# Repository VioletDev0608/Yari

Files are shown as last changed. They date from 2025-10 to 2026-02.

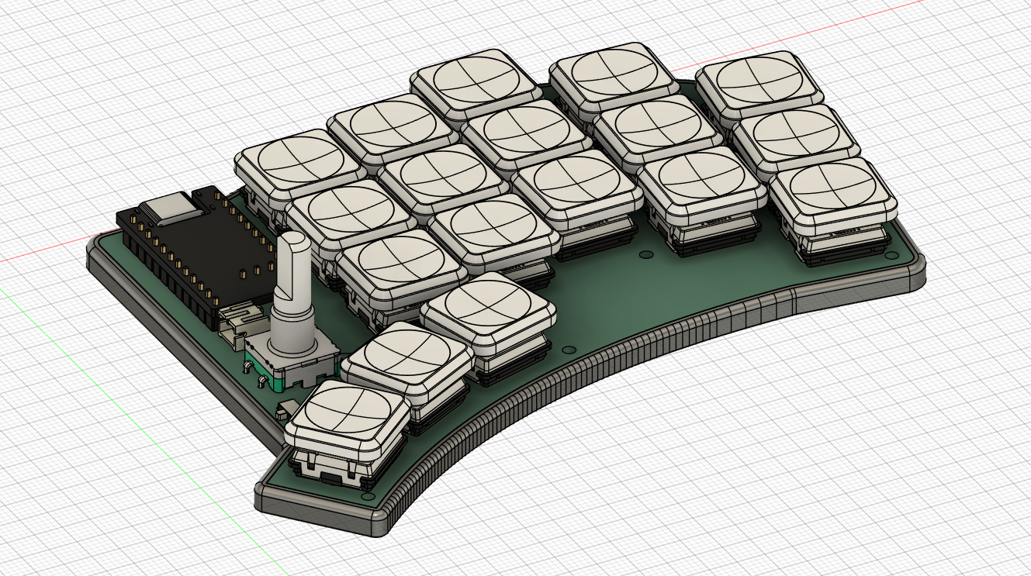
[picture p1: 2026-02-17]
images/image7.png

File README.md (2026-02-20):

# Yari
Yari is a 36-key column-staggered choc split keyboard. It is designed to reduce the required thumb movement beneath the palm.
It has 1 LED to indicate battery levels, splayed pinky and row columns, and is meant to be used with two Supermini nRF52840 microcontrollers. It features an EC11 rotary encoder and extra key on the left half that can be used to switch layers, etc.

## Features:
- 37 Keys
- Column staggered
- Choc v1
- Splayed pinky and row columns
- 1 LED for battery indication
- ZMK support
- Wireless
- EC11 Rotary Encoder

## CAD Model:

The case is a open style with no walls surrounding the switches and just a simple tray to mount the keyboard to and prevent dust from getting into the assembly.
The assembly itself is quite simple
Use a soldering iron to heat up the threaded screw inserts and help it melt its way into the slightly undersized standoff holes. Secure the PCB using the M2 screws. 



Added a version with a split case design with holes at the power button and a cutout at the MCU.


## PCB

PCB was made entirely in Kicad and rotated to minimize the costs when fabricating the PCB. 
There are some quotes on the palm so check it out!





## Firmware

Firmware is based on ZMK!
Hasn't been tested yet...

## BOM

Check [BOM.csv](https://github.com/VioletDev0608/Yari/blob/main/BOM/BOM%20-%20Yari.csv) for all parts needed to build this keyboard!
It comes out to about 98 dollars using aliexpress and JLCPCB to fabricate the PCB!

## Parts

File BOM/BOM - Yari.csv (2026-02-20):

Product Name | Model Name | Quantity | Column 1 | Total Price | Links
PCB |  | 2 |  | $14.00
MCU | Supermini nRF52840 | 2 |  | $9.00 | https://ja.aliexpress.com/item/1005006035267231.html
Switches | Choc V1 | 37 |  | $20.00 | https://ja.aliexpress.com/item/1005008943998118.html
Diodes | 1N4148W(SOD123 Package) | 37 |  | $1.00 | https://ja.aliexpress.com/item/1005008841989543.html
Keycaps | Choc V1 compatible | 37 |  | $15.00 | https://ja.aliexpress.com/item/1005009410193865.html
Reset Button | B3U-1000P | 2 |  | $5.00 | https://ja.aliexpress.com/item/1005007149637345.html
Power Switch | MSK12C02 | 2 |  | $3.00 | https://ja.aliexpress.com/item/1005006710234187.html
Battery | 301230 Lipo Battery | 2 |  | $10.00 | https://ja.aliexpress.com/item/1005008947414547.html
JST connector | JST PH2.0 2 Pin terminal Female socket BENT PIN SOCKET | 2 |  | $3.00 | https://ja.aliexpress.com/item/1005007441813591.html
LED | SK6812mini-e | 2 |  | $2.00 | https://ja.aliexpress.com/item/1005008308801366.html
Sockets | Kalih choc v1 | 37 |  | $5.00 | https://ja.aliexpress.com/item/1005008928238101.html
Rubber feet |  |  |  | $4.00 | https://ja.aliexpress.com/item/1005006455782191.html
Threaded screw inserts | M2x3x3.2 | 34 |  | $3.00 | https://ja.aliexpress.com/item/1005008318533389.html
M2 laptop-style flathead screws | M2x3 | 34 |  | $2.00 | https://ja.aliexpress.com/item/1005008504707668.html
Rotary Encoder | EC11 | 1 |  | $3.00 | https://ja.aliexpress.com/item/1005009120433387.html
Total Price |  |  |  | $99.00
Other stuff needed
3D printed case

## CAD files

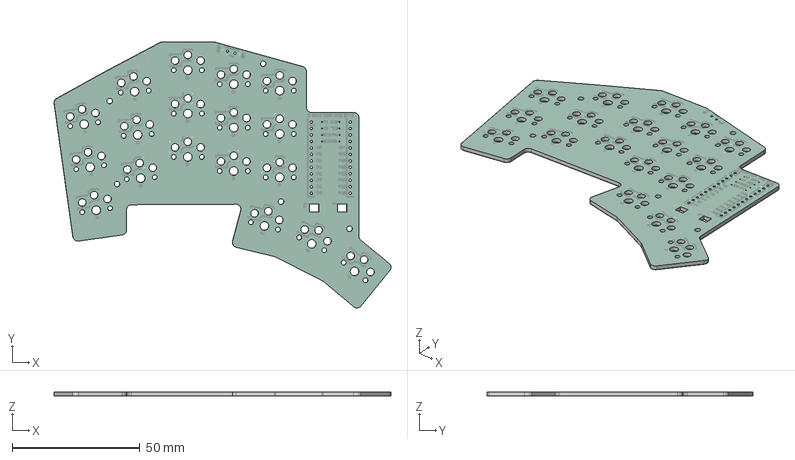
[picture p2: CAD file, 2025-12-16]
CAD/assembled.step
132.0 x 104.2 x 1.66 mm

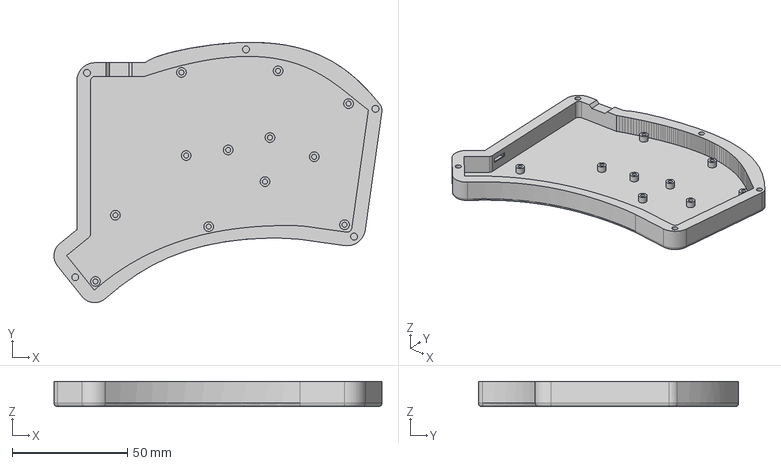
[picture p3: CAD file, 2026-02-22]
CAD/Right Top Case Bottom.step
142.0 x 112.7 x 11.0 mm

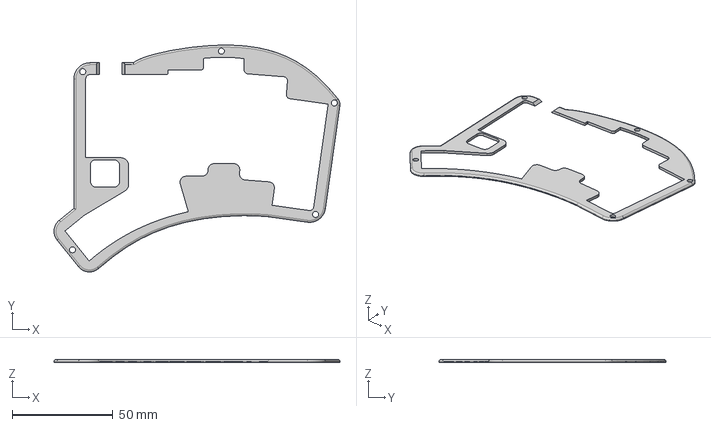
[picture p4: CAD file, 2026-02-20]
CAD/Right Top Case Top.step
142.0 x 112.7 x 1.50 mm

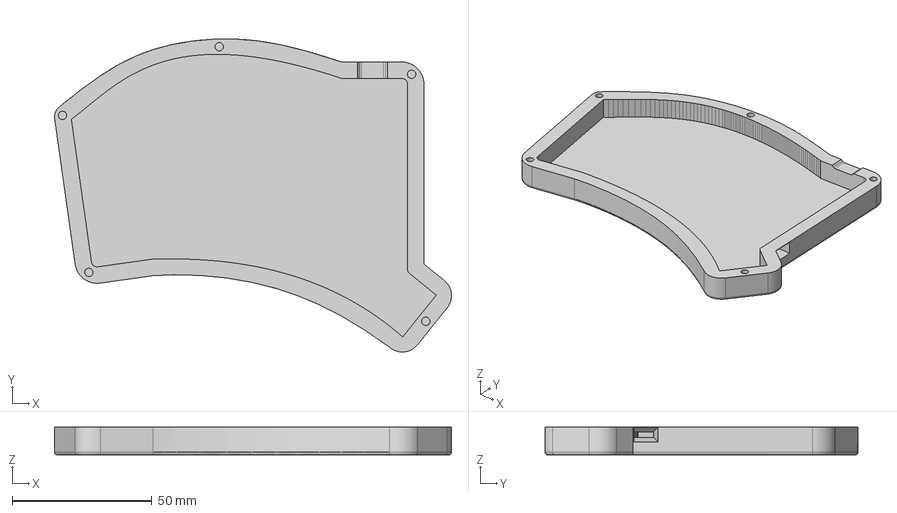
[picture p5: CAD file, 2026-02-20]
CAD/Left Top Case Bottom.step
142.2 x 112.1 x 10.0 mm

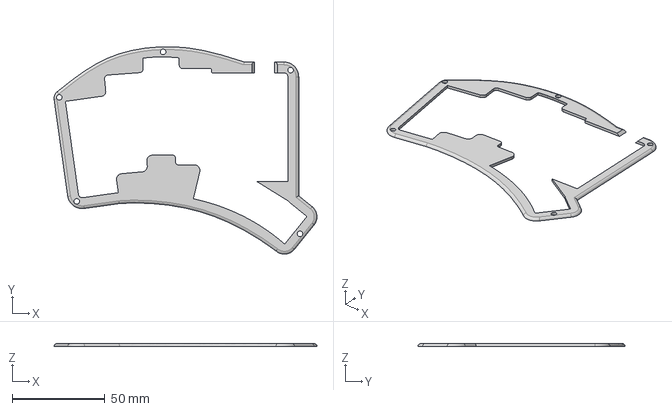
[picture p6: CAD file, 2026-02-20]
CAD/Left Top Case Top.step
142.2 x 112.1 x 1.50 mm

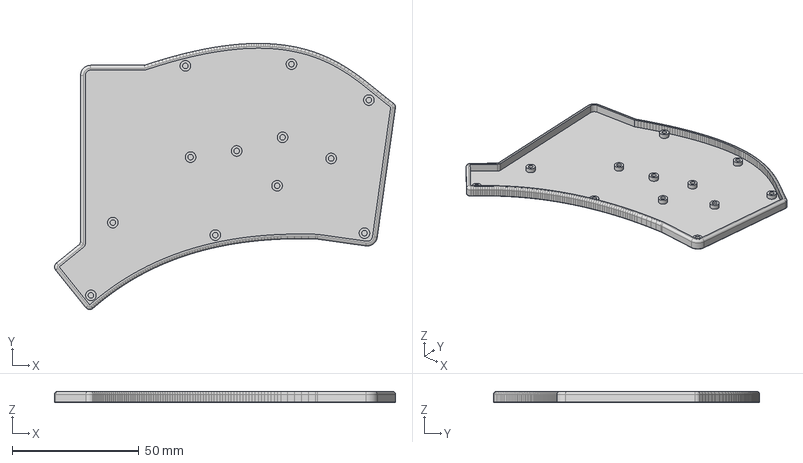
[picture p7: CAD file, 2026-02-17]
CAD/right_case.step
134.4 x 104.9 x 4.51 mm

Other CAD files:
CAD/left_case.step

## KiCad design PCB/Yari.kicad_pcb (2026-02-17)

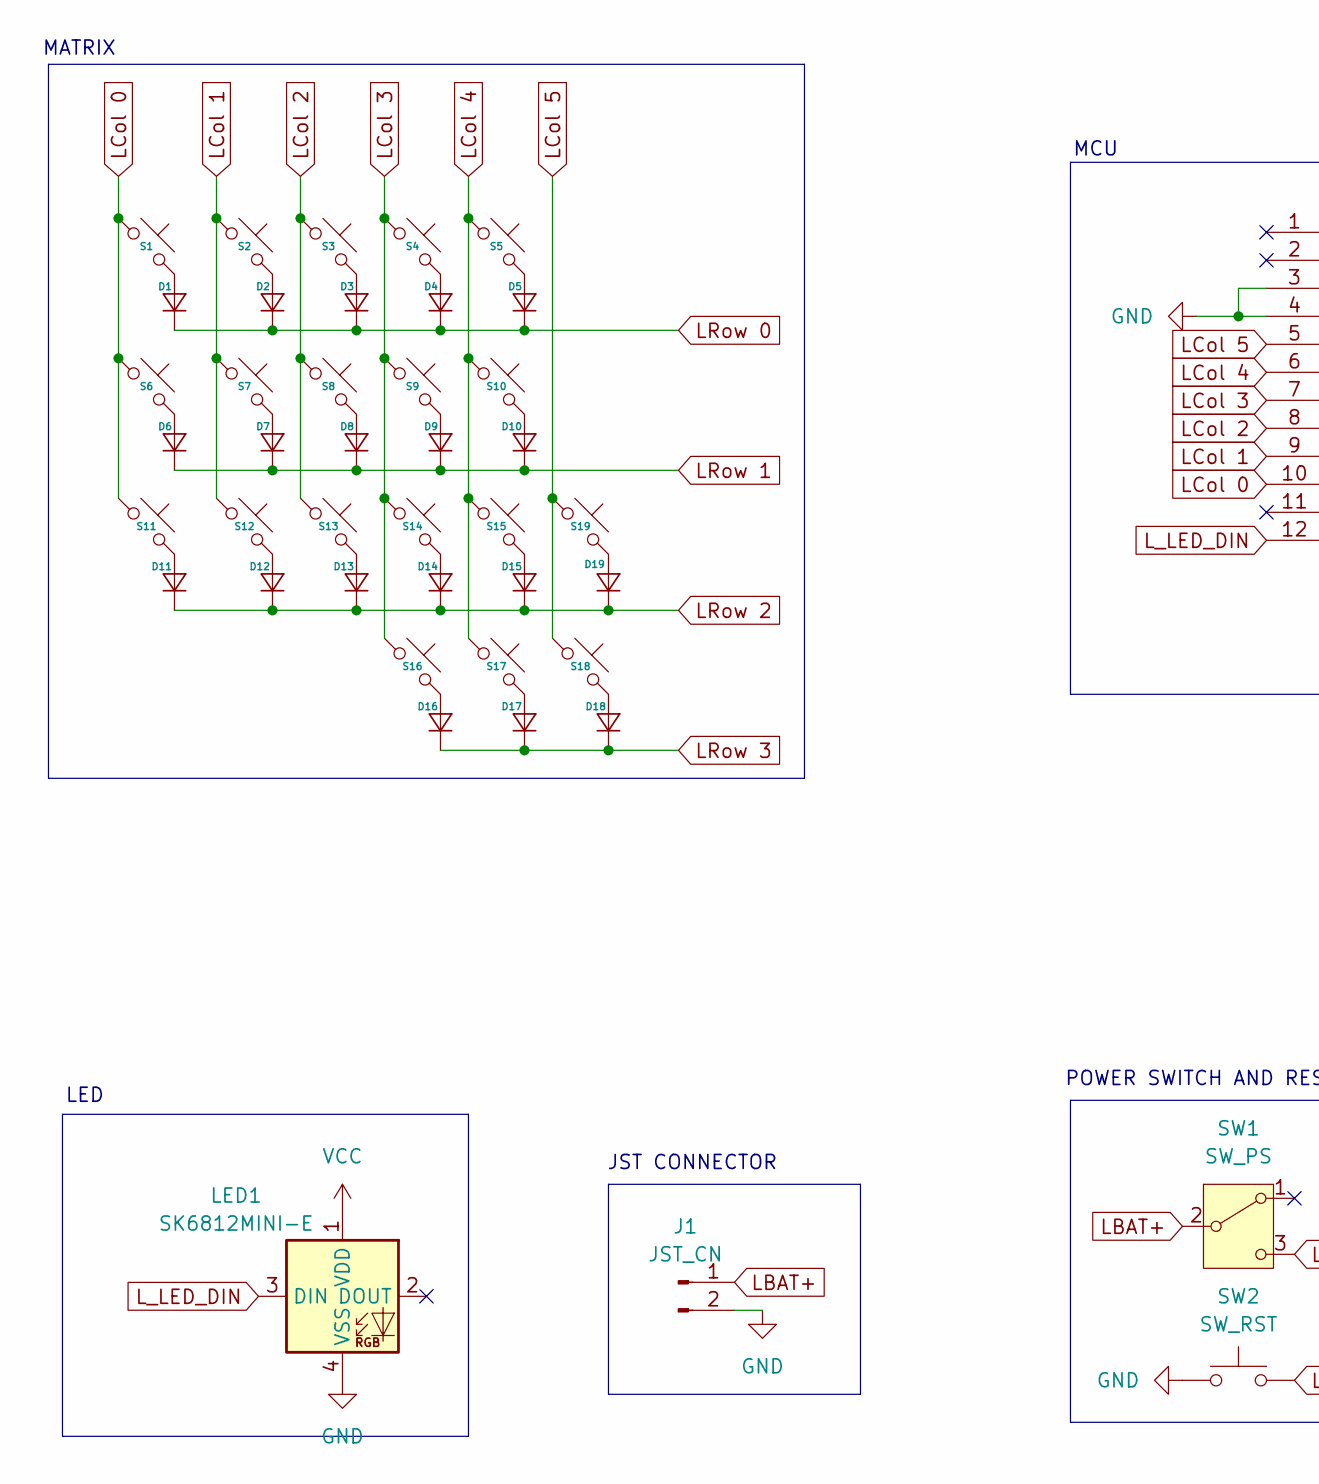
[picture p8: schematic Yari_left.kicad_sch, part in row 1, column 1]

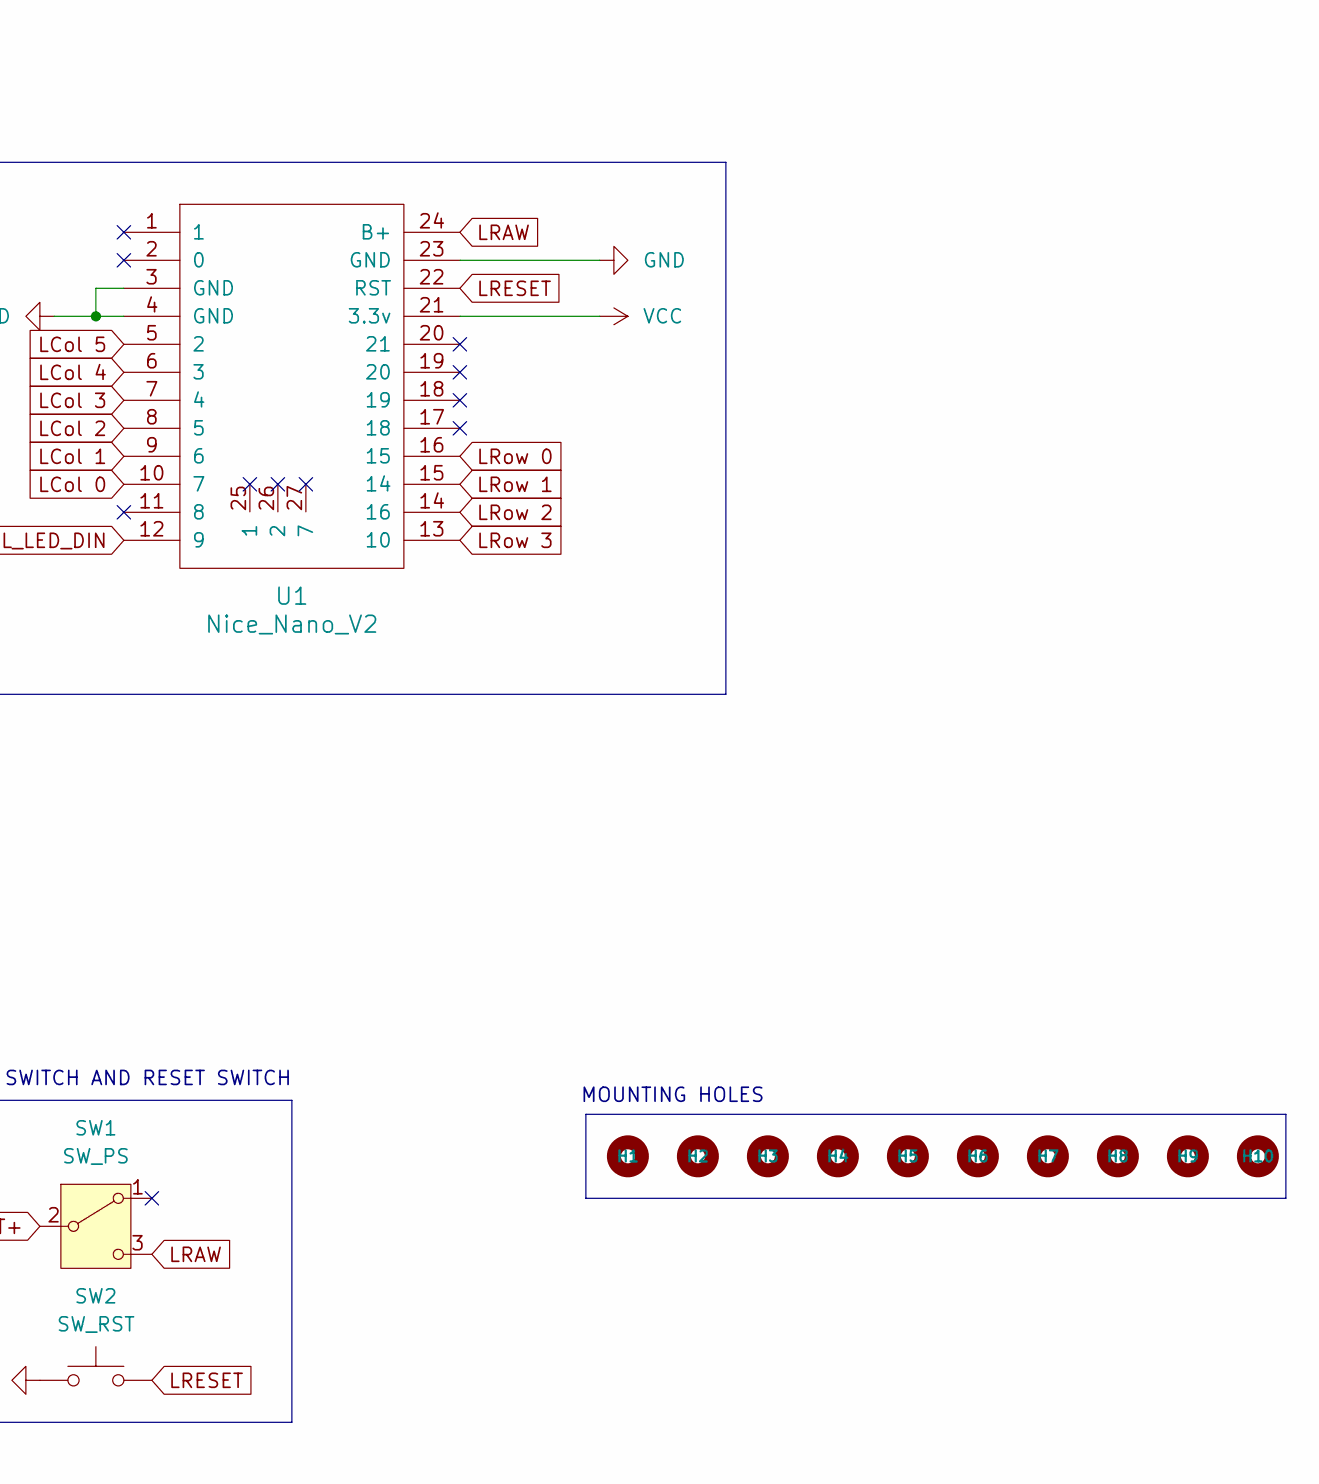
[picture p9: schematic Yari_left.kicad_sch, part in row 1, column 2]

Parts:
D1, D2, D3, D4, D5, D6, D7, D8, D9, D10, D11, D12, D13, D14, D15, D16, D17, D18, D19: Diode_SOD-123
H1, H2, H3, H4, H5, H6, H7, H8, H9, H10: MountingHole_2.2mm_M2_DIN965
J1: JST_CN; JST_PH_S2B-PH-K_1x02_P2.00mm_Horizontal
LED1: SK6812MINI-E; LED_6028R
S1, S2, S3, S4, S5, S6, S7, S8, S9, S10, S11, S12, S13, S14, S15, S16, S17, S18, S19: Hotswap_Choc_V1_1.00u
SW1: SW_PS; SW_MSK12C02-HB
SW2: SW_RST; SW_SPST_B3U-1000P
U1: Nice_Nano_V2; Nice_Nano_V2_Flipped

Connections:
GND: J1.2, LED1.4 (VSS), SW2.1, U1.3 (GND), U1.4 (GND), U1.23 (GND); also elsewhere on the board
LBAT+: J1.1, SW1.2 (B)
LCol 0: S1.1, S6.1, S11.1, U1.10 (7)
LCol 1: S2.1, S7.1, S12.1, U1.9 (6)
LCol 2: S3.1, S8.1, S13.1, U1.8 (5)
LCol 3: S4.1, S9.1, S14.1, S16.1, U1.7 (4)
LCol 4: S5.1, S10.1, S15.1, S17.1, U1.6 (3)
LCol 5: S18.1, S19.1, U1.5 (2)
LRAW: SW1.3 (C), U1.24 (B+)
LRESET: SW2.2, U1.22 (RST)
LRow 0: D1.1 (K), D2.1 (K), D3.1 (K), D4.1 (K), D5.1 (K), U1.16 (15)
LRow 1: D6.1 (K), D7.1 (K), D8.1 (K), D9.1 (K), D10.1 (K), U1.15 (14)
LRow 2: D11.1 (K), D12.1 (K), D13.1 (K), D14.1 (K), D15.1 (K), D19.1 (K), U1.14 (16)
LRow 3: D16.1 (K), D17.1 (K), D18.1 (K), U1.13 (10)
L_LED_DIN: LED1.3 (DIN), U1.12 (9)
unnamed: D1.2 (A), S1.2
unnamed: D2.2 (A), S2.2
unnamed: D3.2 (A), S3.2
unnamed: D4.2 (A), S4.2
unnamed: D5.2 (A), S5.2
unnamed: D6.2 (A), S6.2
unnamed: D7.2 (A), S7.2
unnamed: D8.2 (A), S8.2
unnamed: D9.2 (A), S9.2
unnamed: D10.2 (A), S10.2
unnamed: D11.2 (A), S11.2
unnamed: D12.2 (A), S12.2
unnamed: D13.2 (A), S13.2
unnamed: D14.2 (A), S14.2
unnamed: D15.2 (A), S15.2
unnamed: D16.2 (A), S16.2
unnamed: D17.2 (A), S17.2
unnamed: D18.2 (A), S18.2
unnamed: D19.2 (A), S19.2
VCC: LED1.1 (VDD), U1.21 (3.3v); also elsewhere on the board

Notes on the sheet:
MATRIX
JST CONNECTOR
POWER SWITCH AND RESET SWITCH
MCU
MOUNTING HOLES
LED

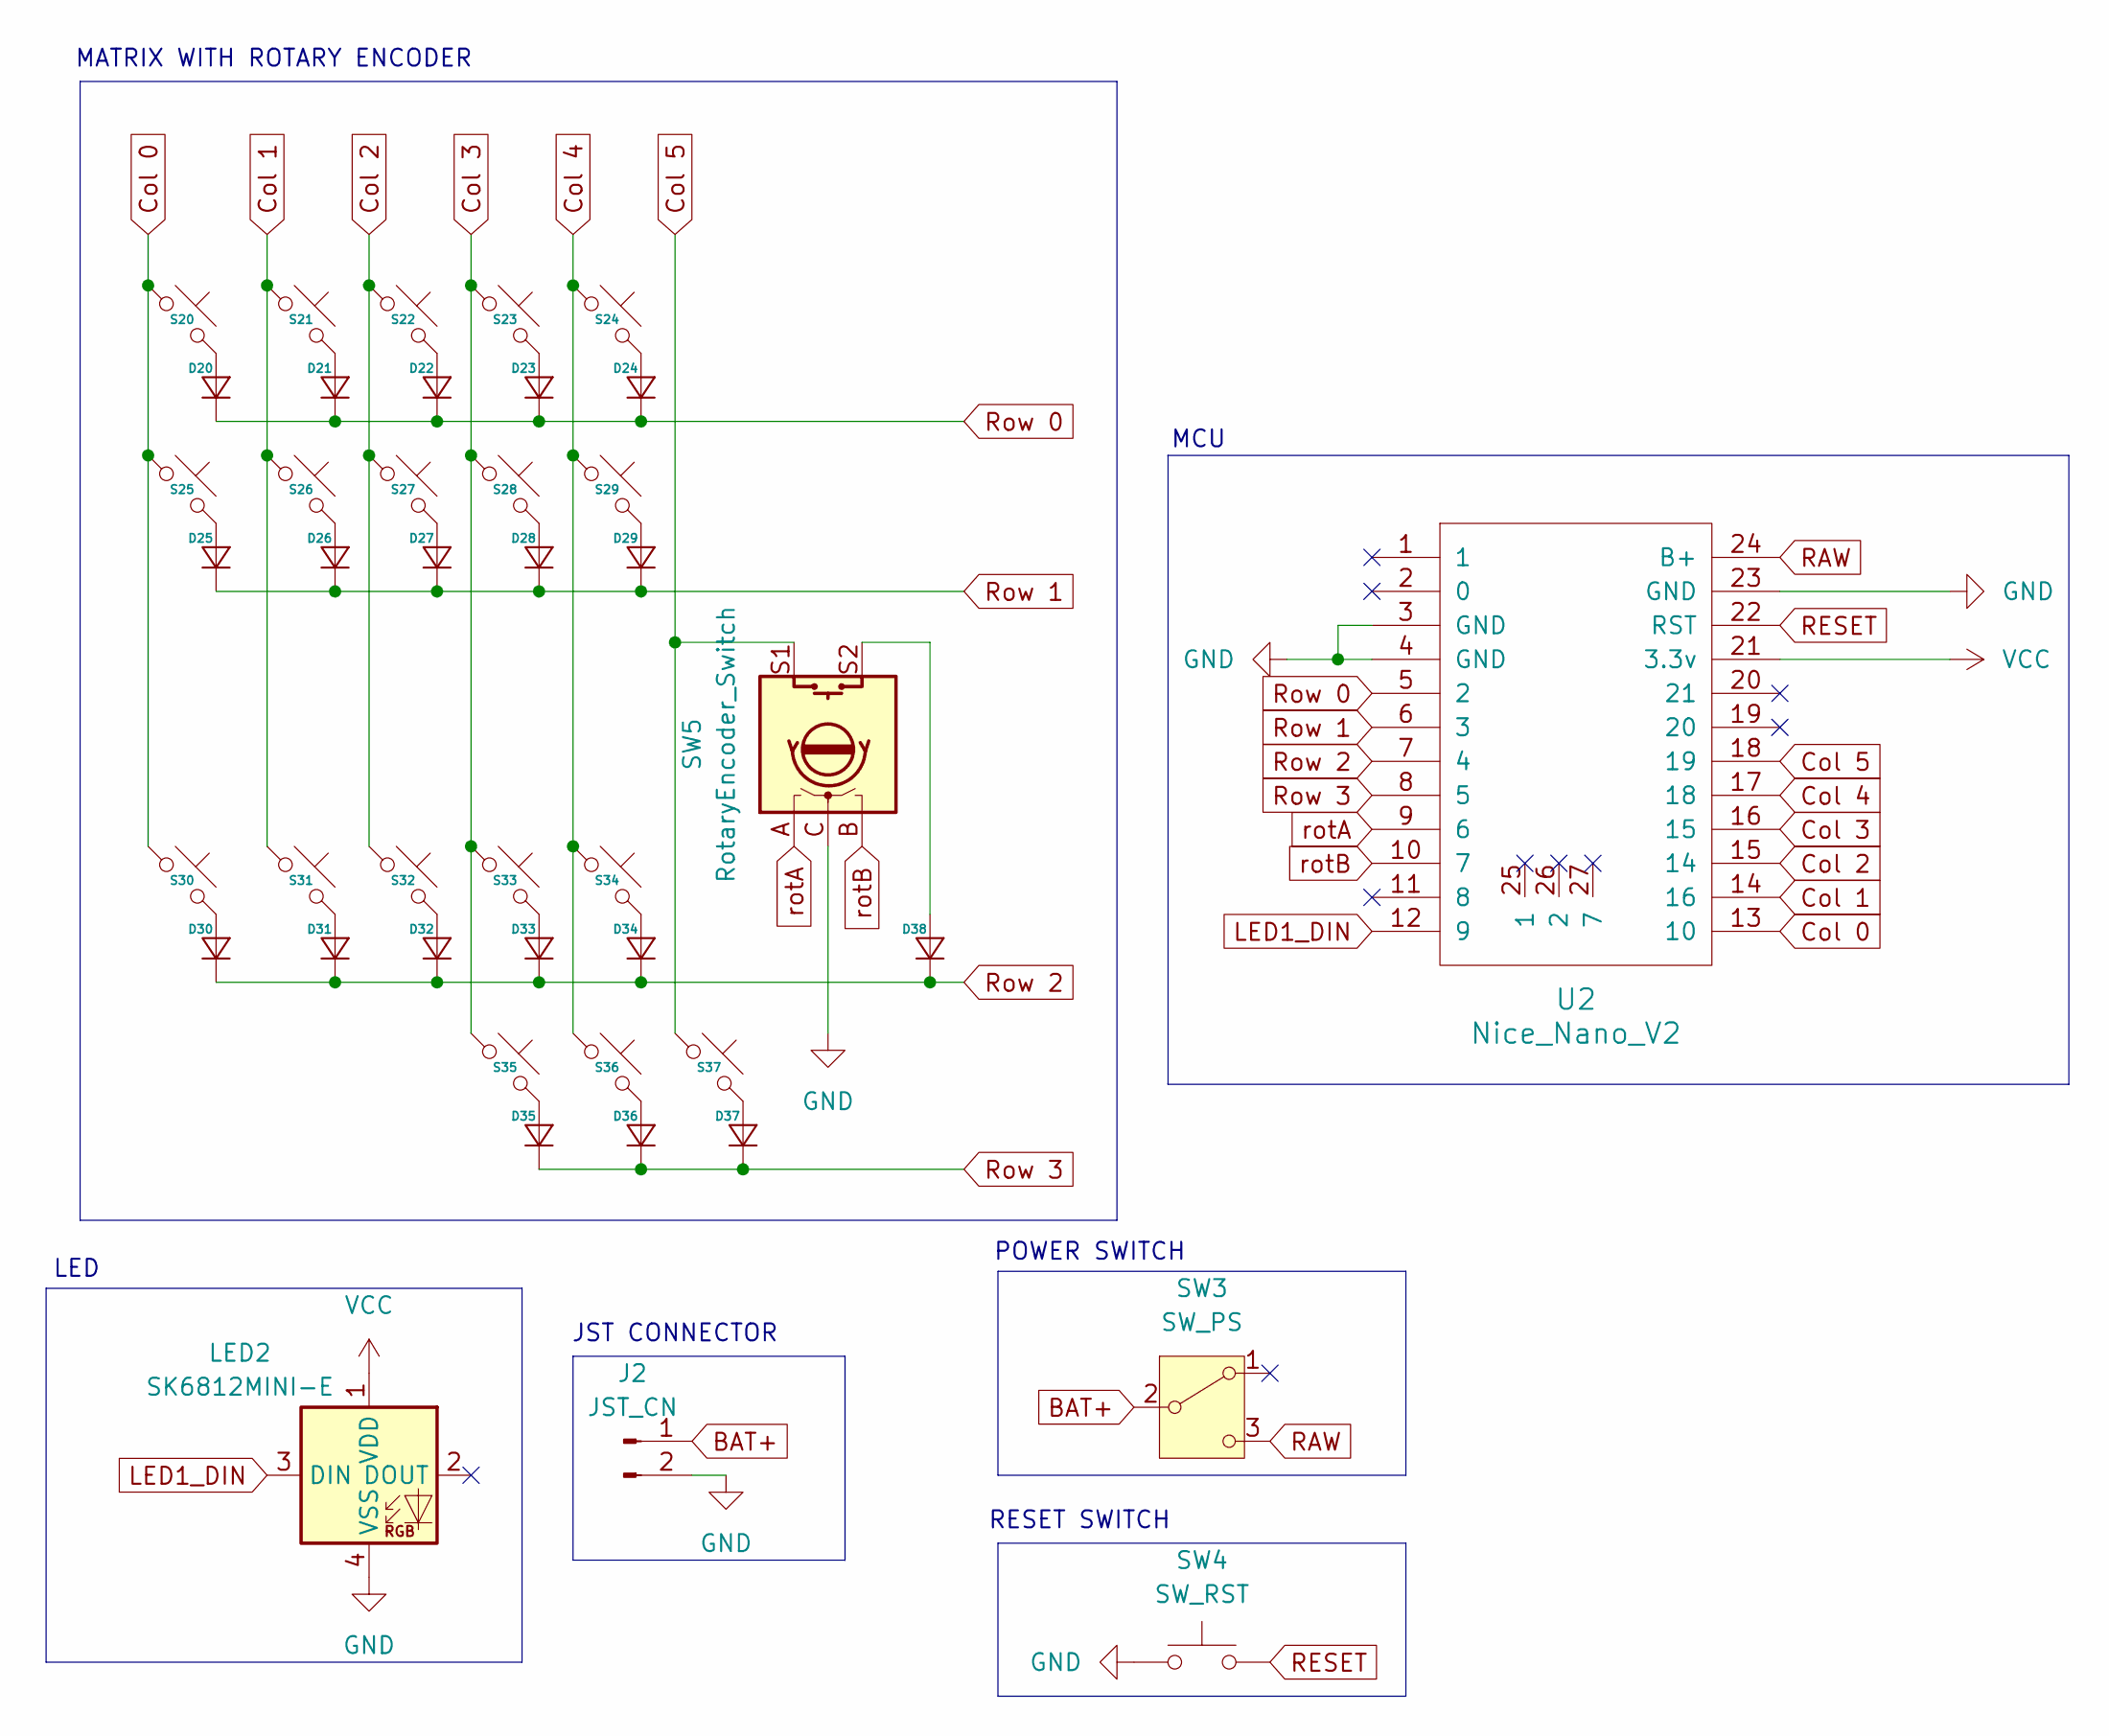
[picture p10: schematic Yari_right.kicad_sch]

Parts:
D20, D21, D22, D23, D24, D25, D26, D27, D28, D29, D30, D31, D32, D33, D34, D35, D36, D37, D38: Diode_SOD-123
J2: JST_CN; JST_PH_S2B-PH-K_1x02_P2.00mm_Horizontal
LED2: SK6812MINI-E; LED_6028R
S20, S21, S22, S23, S24, S25, S26, S27, S28, S29, S30, S31, S32, S33, S34, S35, S36, S37: Hotswap_Choc_V1_1.00u
SW3: SW_PS; SW_MSK12C02-HB
SW4: SW_RST; SW_SPST_B3U-1000P
SW5: RotaryEncoder_Switch; ROT_Alps_EC11E-Switch
U2: Nice_Nano_V2; Nice_Nano_V2_Flipped

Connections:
BAT+: J2.1, SW3.2 (B)
Col 0: S20.1, S25.1, S30.1, U2.13 (10)
Col 1: S21.1, S26.1, S31.1, U2.14 (16)
Col 2: S22.1, S27.1, S32.1, U2.15 (14)
Col 3: S23.1, S28.1, S33.1, S35.1, U2.16 (15)
Col 4: S24.1, S29.1, S34.1, S36.1, U2.17 (18)
Col 5: S37.1, SW5.S1, U2.18 (19)
GND: J2.2, LED2.4 (VSS), SW4.1, SW5.C, U2.3 (GND), U2.4 (GND), U2.23 (GND); also elsewhere on the board
LED1_DIN: LED2.3 (DIN), U2.12 (9)
unnamed: D20.2 (A), S20.2
unnamed: D21.2 (A), S21.2
unnamed: D22.2 (A), S22.2
unnamed: D23.2 (A), S23.2
unnamed: D24.2 (A), S24.2
unnamed: D25.2 (A), S25.2
unnamed: D26.2 (A), S26.2
unnamed: D27.2 (A), S27.2
unnamed: D28.2 (A), S28.2
unnamed: D29.2 (A), S29.2
unnamed: D30.2 (A), S30.2
unnamed: D31.2 (A), S31.2
unnamed: D32.2 (A), S32.2
unnamed: D33.2 (A), S33.2
unnamed: D34.2 (A), S34.2
unnamed: D35.2 (A), S35.2
unnamed: D36.2 (A), S36.2
unnamed: D37.2 (A), S37.2
unnamed: D38.2 (A), SW5.S2
RAW: SW3.3 (C), U2.24 (B+)
RESET: SW4.2, U2.22 (RST)
Row 0: D20.1 (K), D21.1 (K), D22.1 (K), D23.1 (K), D24.1 (K), U2.5 (2)
Row 1: D25.1 (K), D26.1 (K), D27.1 (K), D28.1 (K), D29.1 (K), U2.6 (3)
Row 2: D30.1 (K), D31.1 (K), D32.1 (K), D33.1 (K), D34.1 (K), D38.1 (K), U2.7 (4)
Row 3: D35.1 (K), D36.1 (K), D37.1 (K), U2.8 (5)
VCC: LED2.1 (VDD), U2.21 (3.3v); also elsewhere on the board
rotA: SW5.A, U2.9 (6)
rotB: SW5.B, U2.10 (7)

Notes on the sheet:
LED
MATRIX WITH ROTARY ENCODER
MCU
POWER SWITCH
RESET SWITCH
JST CONNECTOR

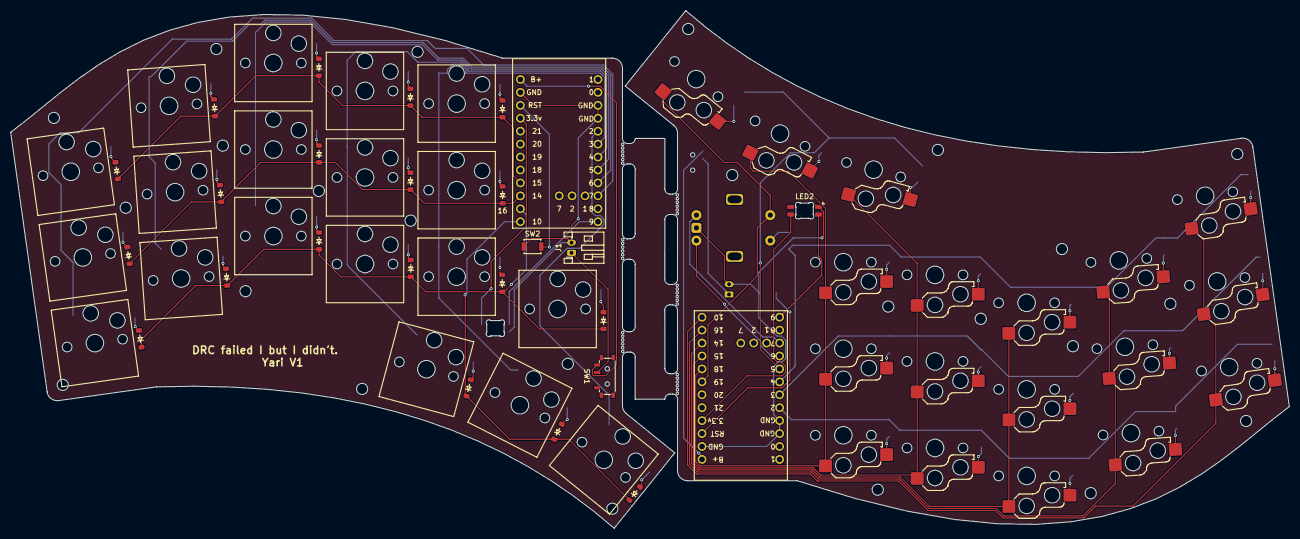
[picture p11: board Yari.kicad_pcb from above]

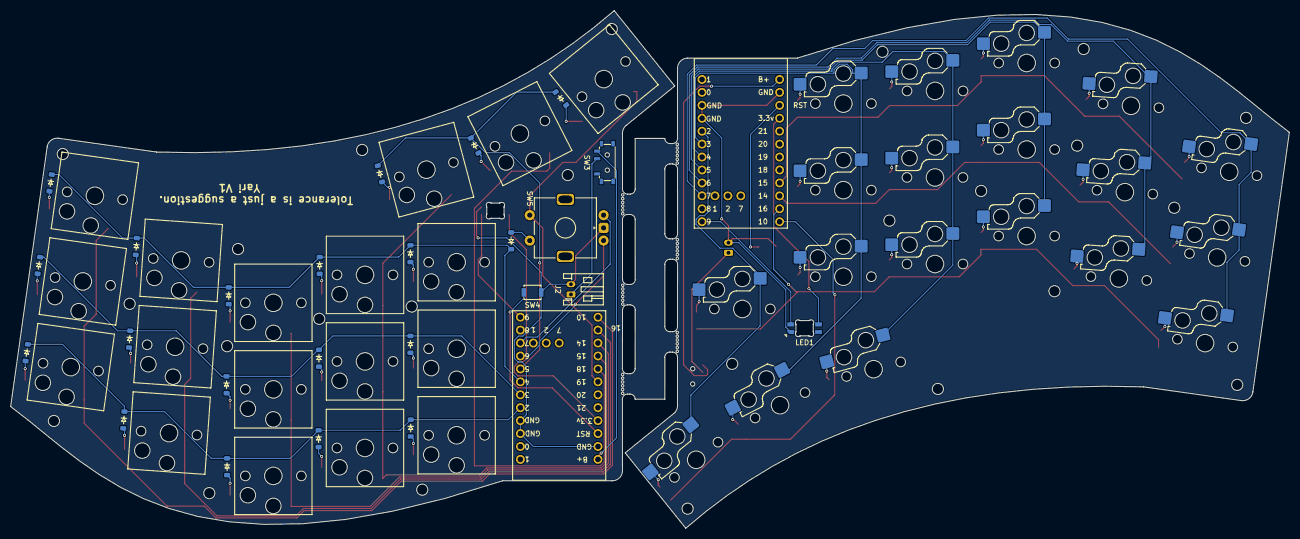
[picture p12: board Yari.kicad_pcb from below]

Board: 2 copper layers, 251.2 x 101.7 mm, 110 parts (45 on the bottom side), 70 nets.

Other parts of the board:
H1#2, H2#2, H3#2, H4#2, H5#2, H6#2, H6#3, H6#4, H6#5, H6#6, H7#2, H8#2, H9#2, H10#2: MountingHole_2.2mm_M2_DIN965

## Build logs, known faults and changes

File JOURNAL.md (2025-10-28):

<!--
  ===================    !!READ THIS NOTICE!!   ====================
  DO NOT edit this file manually. Your changes WILL BE OVERWRITTEN!
  This journal is auto generated and updated by Hack Club Blueprint.
  To edit this file, please edit your journal entries on Blueprint.
  ==================================================================
-->

## 10/24/2025 - Ergogen Basics  

First journal!!
Thank you all at hack club for hosting such thing as blueprint for teens to get a chance to build what they always dreamed of.

I read through the ergogen documentation, trying to follow step by step what they were doing and watched Ben Vallack's tutorial on how to operate it.
Watched the presentation by the creator of ergogen to get a grasp on what the software was originally made for doing. After that, since I had thought I wanted to make an ergonomic keyboard that felt like a laptop so I did some research if I could hand solder those switches. I saw some users on reddit saying it would be quite difficult without an oven so I decided to compromise and use normal choc low profile switches for this build. Played around with the Absolem template because it was the simplest one I could find that used a lot of ergogen's features. 

I was able to understand the basics of ergogen in this session.
スクリーンショット 2025-10-24 175101.png  

## 10/28/2025 12 AM - Completed Key Layout  

Followed flatfootfox's tutorial on how to get about designing what you want. It was one of the most intuitive and easily understandable tutorials I've followed.
I knew what I kind of wanted design wise:
	**PCB**:
		USB-C compatible
		36 keys
		3 key thumb cluster
		Low profile(choc spaced)
		Reversible PCB for lower cost
		Columns staggered
		Ortholinear
		Wireless
		(Diode-less) Optional but preferred for ease of building and cheaper costs
		Angled pinky and ring finger columns
		(Hotswap capabilities)
	**Case**:
		An option to go caseless
		Magsafe tenting compatibility
		(Tenting puck compatibility) Probably wont work on it unless magsafe ends up not working	
The idea of having a keyboard custom tailored to my hands always seemed appealing to me. So I adjusted the stagger and drew it on a paper to see how it would feel to type on it.(My notebook was a 6mm grid so it worked flawlessly for this project). Had some trouble understanding how the splay thing worked but asked some nice fellas in the Absolem Discord server simplified it for me so it was easier for me to understand. 
For future reference:
	`spread`: horizontal padding
	`splay`: rotation
	`stagger`: vertical movement
	`origin` controls: the point where to start
Excited since it's starting to take properly take shape!!!
スクリーンショット 2025-10-28 002912

## 10/28/2025 10 PM - Completed Outlines, Learned about the two duplex matrix's  

スクリーンショット 2025-10-28 212738

Looking back, it probably would've been faster if I made it based on the `raw.dxf`, an outline generated based on the position of the switches but I made a completely new outline called `board.dxf` and manually set all the points in the code which took some time but on the flip side, I think it turned out very clean. Haven't got to the point where you do the electronics so I'm still not sure if I need to adjust the outlines so that there's space to place the mcu on. Considered placing it on the dead space below the staggered keys but I figured it would get in the way.

On flatfootfox's tutorial, it was mentioned that there were two duplex matrix's so I read the article linked on there.

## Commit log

2025-12-16 Added images to README
    Added images and additional details to the CAD model, PCB, and firmware sections.
2026-01-14 Updated render images and added gerber files
    [Yari.kicad_pcb, right_case.stl]
2026-01-20 Updated Images for CAD models
2026-01-20 Added BOM.csv and converted STL files to STEP
    [BOM.csv, case.step, case.stl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]
2026-02-17 Started over in Kicad
    [BOM - Yari.csv, BOM.csv, Yari.kicad_pcb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]
2026-02-17 Revise Yari keyboard specifications and BOM details
    Updated specifications for the Yari keyboard, including changes to the number of keys, LEDs, and PCB details. Added images and a link to the BOM for building the keyboard.
2026-02-19 Top Case STL and images
    [Left Top Case.step, Right Top Case.step]
2026-02-19 Rename スクリーンショット 2026-02-19 234503.png to image16.png
2026-02-19 Add case version with proper walls and button holes
    Added a new version of the case with proper walls and holes for the MCU and power buttons.
2026-02-20 Top Case Update and BOM links
    [BOM - Yari.csv, Left Top Case Bottom.step, Left Top Case Top.step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]
2026-02-20 Update case description and image for split design
2026-02-22 Fixed the hole in Right Top Case Bottom
    [Right Top Case Bottom.step]
